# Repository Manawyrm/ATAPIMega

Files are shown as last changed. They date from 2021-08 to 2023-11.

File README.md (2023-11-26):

ATAPIMega
=============================
PCB photo

### Overview

[ATAPIMega](https://github.com/Manawyrm/ATAPIMega) is a hardware project which allows regular (P)ATA CD/DVD drives to be used as a standalone Audio-CD player.  
This repository contains KiCAD PCB design and schematic for the CD player.  

The PCB accepts (regulated!) 12V DC power via a 5.5mm/2.1mm barrel jack and outputs 12V/5V for the CD drive.  
The microcontroller is an ATmega2560 (Arduino Mega-compatible), chosen for 5V-I/O voltage and high pin-count (and bad availability of STM32's in the component shortage of 2021).

### Manufacturing
The PCB can be fully assembled at [JLCPCBs](https://jlcpcb.com/DDE) assembly service, including through-hole parts. Only the LCD will have to be installed manually.
Manufacturing files for automatic assembly service can be found at `gerbers/RevA/ATAPIMega/`.  

Due to the high amount of extended components, setup fees are quite high (~30$).  
Price will decrease significantly with higher board count (~15$/board).

### Additional info 

[Schematic](gerbers/RevA/ATAPIMega/ATAPIMega.pdf)  
[Interactive BOM](https://tbspace.de/content/downloads/atapimega-ibom-reva.html)  
[Firmware](https://github.com/Manawyrm/ATAPIMega-Firmware)  

### Errata
Rev.A: FTDI / UART connector reset circuitry is wrong, needs bodge resistor!

### Future improvements
- mounting holes
- labeling of audio ports (LGGR, etc.)
- power switch

### Credits
5V Step-Down switch-mode regulator was designed with a lot of help from [@Toble_Miner](https://github.com/TobleMiner)! Thanks!

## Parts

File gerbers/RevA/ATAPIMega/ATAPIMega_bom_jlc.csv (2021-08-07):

Comment | Designator | Footprint | LCSC Part #
100nF | C5,C4,C6,C7,C8,C11,C2 | C_0402_1005Metric | C1525
22uF | C10,C9,C13,C12 | C_0805_2012Metric | C45783
22pF | C14,C1,C3 | C_0402_1005Metric | C1555
2200uF 16V | C15 | CP_Radial_D13.0mm_P5.00mm | C88768
LED | D1 | LED_0603_1608Metric | C72043
ISP | J1 | IDC-Header_2x03_P2.54mm_Vertical | C11214
IDE | J2 | IDC-Header_2x20_P2.54mm_Vertical | C9138
UART | J3 | PinHeader_1x06_P2.54mm_Vertical | C37208
Drive_Power | J5 | TerminalBlock_RND_205-00003_1x04_P5.00mm_Horizontal | C192779
12V DC-In | J6 | BarrelJack_DC-005-2.0_C16214 | C16214
3.5mm | J8 | Jack_3.5mm_CUI_SJ1-3535NG_Horizontal | C26230
Audio in | J9 | PinHeader_1x04_P2.54mm_Vertical | C492403
4.7uH | L1 | L_Bourns_SRP7028A_7.3x6.6mm | C207840
75R | R2,R8 | R_0402_1005Metric | C25133
4.7k | R3,R5,R4 | R_0402_1005Metric | C25900
220k | R9 | R_0603_1608Metric | C22961
30k | R10 | R_0603_1608Metric | C22984
10k | R16,R18,R6,R7,R1 | R_0402_1005Metric | C25744
33R | RN3,RN1,RN4,RN2,RN6,RN5 | R_Array_Convex_4x0402 | C25501
10k Contrast | RV1 | Potentiometer_Bourns_3296W_Vertical | C118954
Rew | SW1 | SW_Push_1P1T_NO_6x6mm_H9.5mm | C381038
Prev | SW2 | SW_Push_1P1T_NO_6x6mm_H9.5mm | C381038
Play/Pause | SW3 | SW_Push_1P1T_NO_6x6mm_H9.5mm | C381038
Fwd | SW4 | SW_Push_1P1T_NO_6x6mm_H9.5mm | C381038
Next | SW5 | SW_Push_1P1T_NO_6x6mm_H9.5mm | C381038
Stop/Eject | SW6 | SW_Push_1P1T_NO_6x6mm_H9.5mm | C381038
Shuffle/Repeat | SW7 | SW_Push_1P1T_NO_6x6mm_H9.5mm | C381038
ATmega2560-16AU | U1 | TQFP-100_14x14mm_P0.5mm | C22460
SY8113B | U3 | TSOT-23-6 | C78989
16 MHz | Y1 | Crystal_SMD_3225-4Pin_3.2x2.5mm | C13738

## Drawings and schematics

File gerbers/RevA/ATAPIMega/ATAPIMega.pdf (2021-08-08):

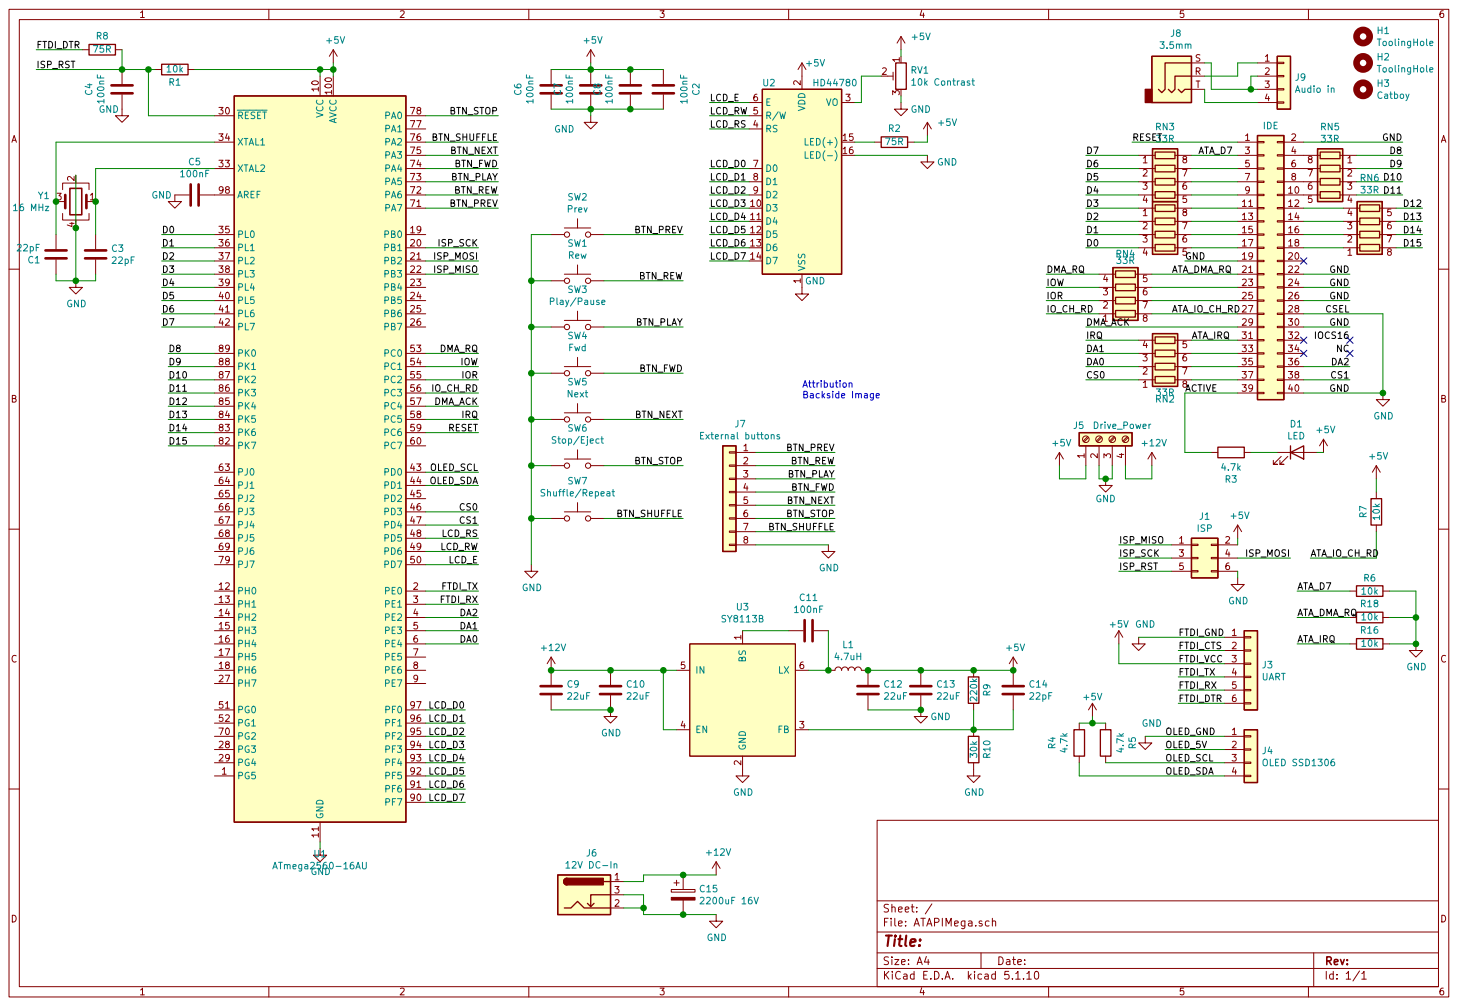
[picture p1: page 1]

File: ATAPIMega.sch Sheet: / C10

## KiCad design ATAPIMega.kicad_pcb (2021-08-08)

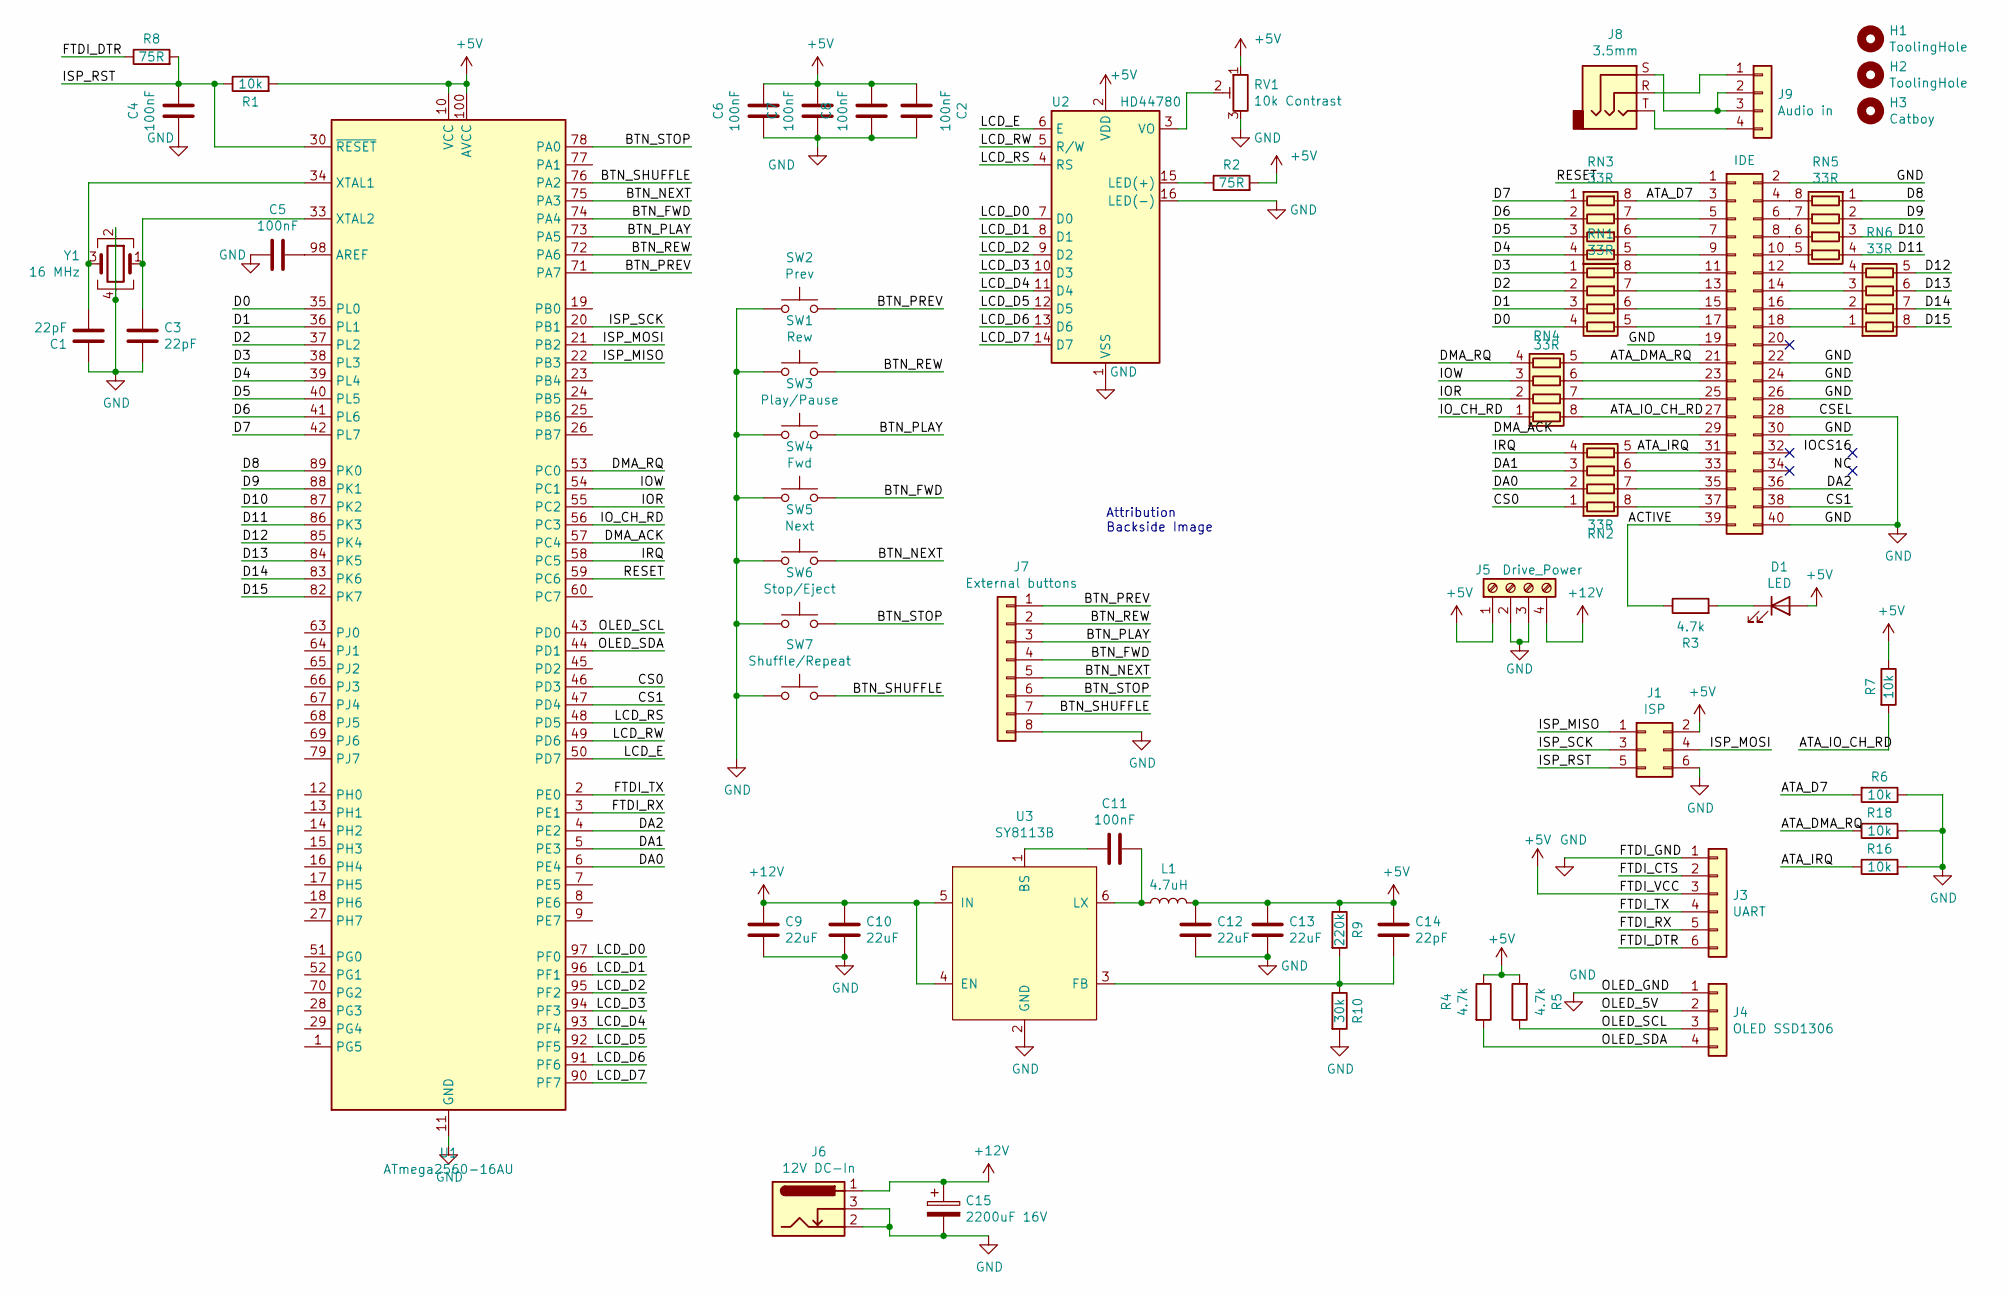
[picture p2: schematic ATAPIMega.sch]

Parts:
C1, C3, C14: 22pF; C_0402_1005Metric; LCSC C1555
C2, C4, C5, C6, C7, C8, C11: 100nF; C_0402_1005Metric; LCSC C1525
C9, C10, C12, C13: 22uF; C_0805_2012Metric; LCSC C45783
C15: 2200uF 16V; CP_Radial_D13.0mm_P5.00mm; LCSC C88768
D1: LED; LED_0603_1608Metric; LCSC C72043
H1, H2: ToolingHole; ToolingHole_JLCSMT
H3: Catboy; catboy
J1: ISP; IDC-Header_2x03_P2.54mm_Vertical; LCSC C11214
J2: IDE; IDC-Header_2x20_P2.54mm_Vertical; LCSC C9138
J3: UART; PinHeader_1x06_P2.54mm_Vertical; LCSC C37208
J4: OLED SSD1306; PinHeader_1x04_P2.54mm_Vertical
J5: Drive_Power; TerminalBlock_RND_205-00003_1x04_P5.00mm_Horizontal; LCSC C192779
J6: 12V DC-In; BarrelJack_DC-005-2.0_C16214; LCSC C16214
J7: External buttons; PinHeader_1x08_P2.54mm_Vertical
J8: 3.5mm; Jack_3.5mm_CUI_SJ1-3535NG_Horizontal; LCSC C26230
J9: Audio in; PinHeader_1x04_P2.54mm_Vertical; LCSC C492403
L1: 4.7uH; L_Bourns_SRP7028A_7.3x6.6mm; LCSC C207840
R1, R6, R7, R16, R18: 10k; R_0402_1005Metric; LCSC C25744
R2, R8: 75R; R_0402_1005Metric; LCSC C25133
R3, R4, R5: 4.7k; R_0402_1005Metric; LCSC C25900
R9: 220k; R_0603_1608Metric; LCSC C22961
R10: 30k; R_0603_1608Metric; LCSC C22984
RN1, RN2, RN3, RN4, RN5, RN6: 33R; R_Array_Convex_4x0402; LCSC C25501
RV1: 10k Contrast; Potentiometer_Bourns_3296W_Vertical; LCSC C118954
SW1: Rew; SW_Push_1P1T_NO_6x6mm_H9.5mm; LCSC C381038
SW2: Prev; SW_Push_1P1T_NO_6x6mm_H9.5mm; LCSC C381038
SW3: Play/Pause; SW_Push_1P1T_NO_6x6mm_H9.5mm; LCSC C381038
SW4: Fwd; SW_Push_1P1T_NO_6x6mm_H9.5mm; LCSC C381038
SW5: Next; SW_Push_1P1T_NO_6x6mm_H9.5mm; LCSC C381038
SW6: Stop/Eject; SW_Push_1P1T_NO_6x6mm_H9.5mm; LCSC C381038
SW7: Shuffle/Repeat; SW_Push_1P1T_NO_6x6mm_H9.5mm; LCSC C381038
U1: ATmega2560-16AU; TQFP-100_14x14mm_P0.5mm; LCSC C22460
U2: HD44780; WC1602A
U3: SY8113B; TSOT-23-6; LCSC C78989
Y1: 16 MHz; Crystal_SMD_3225-4Pin_3.2x2.5mm; LCSC C13738

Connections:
+5V: C2.2, C6.1, C7.1, C8.1, C12.1, C13.1, C14.1, D1.2 (A), J1.2, J3.3, J5.1, L1.2, R1.2, R2.2, R4.1, R5.2, R7.1, R9.1, RV1.1, U1.10 (VCC), U1.31 (VCC), U1.61 (VCC), U1.80 (VCC), U1.100 (AVCC), U2.2 (VDD)
+12V: C9.1, C10.1, C15.1, J5.4, J6.1, U3.4 (EN), U3.5 (IN)
/ACTIVE: J2.39, R3.1
/ATA_D7: J2.3, R6.2, RN3.8 (R1.2)
/ATA_DMA_RQ: J2.21, R18.1, RN4.5 (R4.2)
/ATA_IO_CH_RD: J2.27, R7.2, RN4.8 (R1.2)
/ATA_IRQ: J2.31, R16.1, RN2.5 (R4.2)
/BTN_FWD: J7.4, SW4.2, U1.74 (PA4)
/BTN_NEXT: J7.5, SW5.2, U1.75 (PA3)
/BTN_PLAY: J7.3, SW3.2, U1.73 (PA5)
/BTN_PREV: J7.1, SW2.2, U1.71 (PA7)
/BTN_REW: J7.2, SW1.2, U1.72 (PA6)
/BTN_SHUFFLE: J7.7, SW7.2, U1.76 (PA2)
/BTN_STOP: J7.6, SW6.2, U1.78 (PA0)
/CS0: RN2.1 (R1.1), U1.46 (PD3)
/CS1: J2.38, U1.47 (PD4)
/D0: RN1.4 (R4.1), U1.35 (PL0)
/D1: RN1.3 (R3.1), U1.36 (PL1)
/D2: RN1.2 (R2.1), U1.37 (PL2)
/D3: RN1.1 (R1.1), U1.38 (PL3)
/D4: RN3.4 (R4.1), U1.39 (PL4)
/D5: RN3.3 (R3.1), U1.40 (PL5)
/D6: RN3.2 (R2.1), U1.41 (PL6)
/D7: RN3.1 (R1.1), U1.42 (PL7)
/D8: RN5.1 (R1.1), U1.89 (PK0)
/D9: RN5.2 (R2.1), U1.88 (PK1)
/D10: RN5.3 (R3.1), U1.87 (PK2)
/D11: RN5.4 (R4.1), U1.86 (PK3)
/D12: RN6.5 (R4.2), U1.85 (PK4)
/D13: RN6.6 (R3.2), U1.84 (PK5)
/D14: RN6.7 (R2.2), U1.83 (PK6)
/D15: RN6.8 (R1.2), U1.82 (PK7)
/DA0: RN2.2 (R2.1), U1.6 (PE4)
/DA1: RN2.3 (R3.1), U1.5 (PE3)
/DA2: J2.36, U1.4 (PE2)
/DMA_ACK: J2.29, U1.57 (PC4)
/DMA_RQ: RN4.4 (R4.1), U1.53 (PC0)
/FTDI_CTS: J3.2
/FTDI_DTR: J3.6, R8.1
/FTDI_RX: J3.5, U1.3 (PE1)
/FTDI_TX: J3.4, U1.2 (PE0)
/IOR: RN4.2 (R2.1), U1.55 (PC2)
/IOW: RN4.3 (R3.1), U1.54 (PC1)
/IO_CH_RD: RN4.1 (R1.1), U1.56 (PC3)
/IRQ: RN2.4 (R4.1), U1.58 (PC5)
/ISP_MISO: J1.1, U1.22 (PB3)
/ISP_MOSI: J1.4, U1.21 (PB2)
/ISP_RST: C4.1, J1.5, R1.1, R8.2, U1.30 (~RESET)
/ISP_SCK: J1.3, U1.20 (PB1)
/LCD_D0: U1.97 (PF0), U2.7 (D0)
/LCD_D1: U1.96 (PF1), U2.8 (D1)
/LCD_D2: U1.95 (PF2), U2.9 (D2)
/LCD_D3: U1.94 (PF3), U2.10 (D3)
/LCD_D4: U1.93 (PF4), U2.11 (D4)
/LCD_D5: U1.92 (PF5), U2.12 (D5)
/LCD_D6: U1.91 (PF6), U2.13 (D6)
/LCD_D7: U1.90 (PF7), U2.14 (D7)
/LCD_E: U1.50 (PD7), U2.6 (E)
/LCD_RS: U1.48 (PD5), U2.4 (RS)
/LCD_RW: U1.49 (PD6), U2.5 (R/W)
/OLED_5V: J4.2
/OLED_SCL: J4.3, R5.1, U1.43 (PD0)
/OLED_SDA: J4.4, R4.2, U1.44 (PD1)
/RESET: J2.1, U1.59 (PC6)
GND: C1.1, C2.1, C3.2, C4.2, C5.2, C6.2, C7.2, C8.2, C9.2, C10.2, C12.2, C13.2, C15.2, J1.6, J2.2, J2.19, J2.22, J2.24, J2.26, J2.28, J2.30, J2.40, J3.1, J4.1, J5.2, J5.3, J6.2, J6.3, J7.8, R6.1, R10.2, R16.2, R18.2, RV1.3, SW1.1, SW2.1, SW3.1, SW4.1, SW5.1, SW6.1, SW7.1, U1.11 (GND), U1.32 (GND), U1.62 (GND), U1.81 (GND), U1.99 (GND), U2.1 (VSS), U2.16 (LED(-)), U3.2 (GND), Y1.2, Y1.4
unnamed: C1.2, U1.34 (XTAL1), Y1.3
unnamed: C3.1, U1.33 (XTAL2), Y1.1
unnamed: C5.1, U1.98 (AREF)
unnamed: C11.1, L1.1, U3.6 (LX)
unnamed: C11.2, U3.1 (BS)
unnamed: C14.2, R9.2, R10.1, U3.3 (FB)
unnamed: D1.1 (K), R3.2
unnamed: J2.4, RN5.8 (R1.2)
unnamed: J2.5, RN3.7 (R2.2)
unnamed: J2.6, RN5.7 (R2.2)
unnamed: J2.7, RN3.6 (R3.2)
unnamed: J2.8, RN5.6 (R3.2)
unnamed: J2.9, RN3.5 (R4.2)
unnamed: J2.10, RN5.5 (R4.2)
unnamed: J2.11, RN1.8 (R1.2)
unnamed: J2.12, RN6.4 (R4.1)
unnamed: J2.13, RN1.7 (R2.2)
unnamed: J2.14, RN6.3 (R3.1)
unnamed: J2.15, RN1.6 (R3.2)
unnamed: J2.16, RN6.2 (R2.1)
unnamed: J2.17, RN1.5 (R4.2)
unnamed: J2.18, RN6.1 (R1.1)
unnamed: J2.23, RN4.6 (R3.2)
unnamed: J2.25, RN4.7 (R2.2)
unnamed: J2.33, RN2.6 (R3.2)
unnamed: J2.35, RN2.7 (R2.2)
unnamed: J2.37, RN2.8 (R1.2)
unnamed: J8.R, J9.1
unnamed: J8.S, J9.2, J9.3
unnamed: J8.T, J9.4
unnamed: R2.1, U2.15 (LED(+))
unnamed: RV1.2, U2.3 (VO)

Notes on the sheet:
Attribution Backside Image

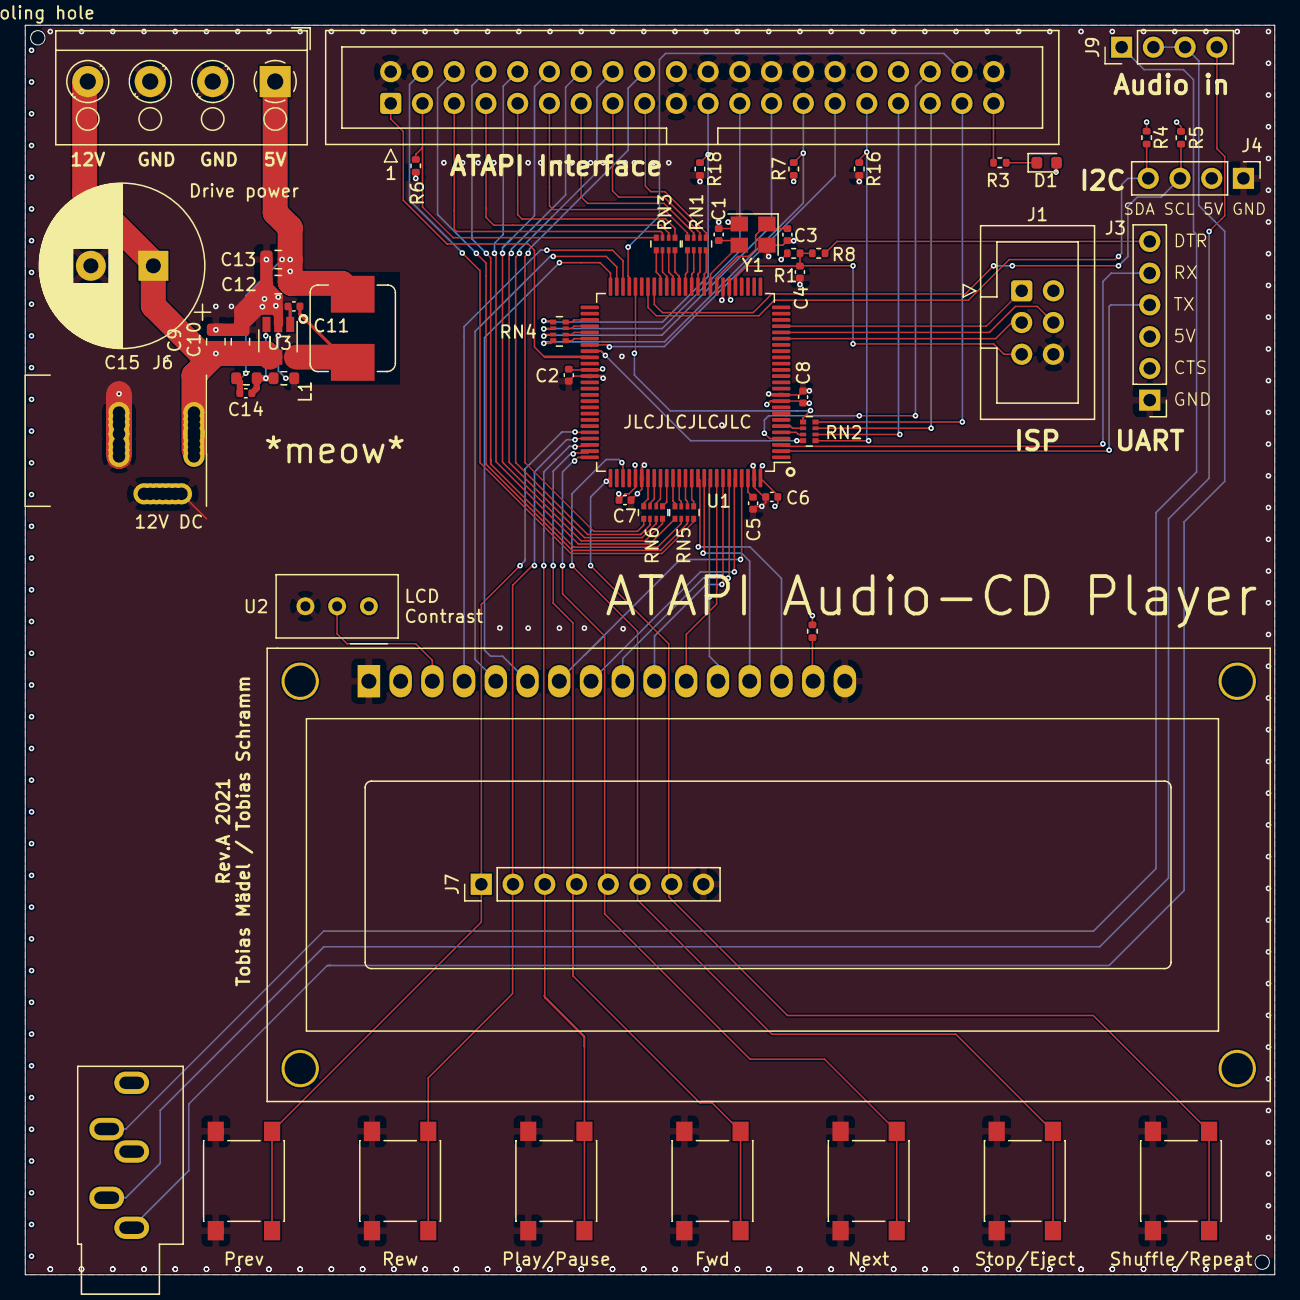
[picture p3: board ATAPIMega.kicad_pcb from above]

Board: 4 copper layers, 100.0 x 100.0 mm, 59 parts (1 on the bottom side), 95 nets.
